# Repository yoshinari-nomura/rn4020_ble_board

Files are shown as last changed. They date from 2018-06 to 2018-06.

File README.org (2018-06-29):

#+TITLE: RN4020 を使った iBeacon 作成
#+AUTHOR: 乃村 能成
#+EMAIL:
#+DATE: 2017-06-30
#+OPTIONS: H:3 num:2 toc:nil
#+OPTIONS: ^:nil @:t \n:nil ::t |:t f:t TeX:t
#+OPTIONS: skip:nil
#+OPTIONS: author:t
#+OPTIONS: email:nil
#+OPTIONS: creator:nil
#+OPTIONS: timestamp:nil
#+OPTIONS: timestamps:nil
#+OPTIONS: d:nil
#+OPTIONS: tags:t
#+TEXT:
#+DESCRIPTION:
#+KEYWORDS:
#+LANGUAGE: ja
#+LATEX_CLASS: jsarticle
#+LATEX_CLASS_OPTIONS: [a4j,dvipdfmx]
# #+LATEX_HEADER: \usepackage{plain-article}
# #+LATEX_HEADER: \renewcommand\maketitle{}
# #+LATEX_HEADER: \pagestyle{empty}
# #+LaTeX: \thispagestyle{empty}

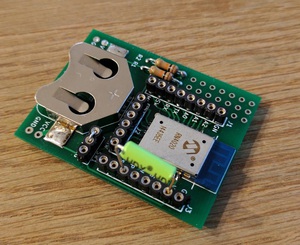
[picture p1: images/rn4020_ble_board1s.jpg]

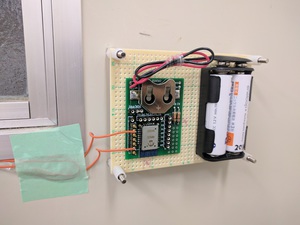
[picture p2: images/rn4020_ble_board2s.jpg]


* はじめに
  Microchip の RN4020 は，Bluetooth Low Energy 機器作成に必要な機能を1チップに収めた
  非常に使いやすいマイコン製品です．以下の特徴があります．

  + 消費電力非常に小さい
  + 簡易的ながら柔軟なユーザスクリプトを記述できる
  + 特別な開発環境(コンパイラ)の整備が不要

* ディレクトリ構成
  + file:TECHNICAL-MEMO.org :: 作成時に気付いたことなどのメモやノウハウ
  + file:README.org :: このファイル
  + file:datasheet/ :: RN4020 のデータシート
  + file:images/ :: 回路図(PDF)，CADの3Dイメージ，設置例写真など
  + file:kicad/ :: 回路図，基板作成CADのデータ
    + file:garber/ :: PCB注文時のzipファイルと作成用シェルスクリプトなど
  + file:rn4020_scripts/ :: RN4020に書込むユーザスクリプト例

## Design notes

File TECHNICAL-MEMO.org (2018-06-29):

#+TITLE: RN4020 を使った beacon 作成メモ
#+AUTHOR: Yoshinari Nomura
#+EMAIL:
#+DATE:
#+OPTIONS: H:3 num:2 toc:nil
#+OPTIONS: ^:nil @:t \n:nil ::t |:t f:t TeX:t
#+OPTIONS: skip:nil
#+OPTIONS: author:t
#+OPTIONS: email:nil
#+OPTIONS: creator:nil
#+OPTIONS: timestamp:nil
#+OPTIONS: timestamps:nil
#+OPTIONS: d:nil
#+OPTIONS: tags:t
#+TEXT:
#+DESCRIPTION:
#+KEYWORDS:
#+LANGUAGE: ja
#+LATEX_CLASS: jsarticle
#+LATEX_CLASS_OPTIONS: [a4j,dvipdfmx]
# #+LATEX_HEADER: \usepackage{plain-article}
# #+LATEX_HEADER: \renewcommand\maketitle{}
# #+LATEX_HEADER: \pagestyle{empty}
# #+LaTeX: \thispagestyle{empty}

* 部品の選定
** RN4020 ← これを選定
   + 秋月で買える ( [[http://akizukidenshi.com/catalog/g/gM-10066/][RN4020-V/RM123]] ) 1,000円ぐらい
   + MCU なしでも簡単な回路でセンサと連携できそう
   + 価格と入手性がいい

** konashi/koshian
   + [[https://www.ux-xu.com/product/konashi][konashi | ユカイ工学]]
   + [[http://eleshop.jp/shop/g/gFAE311/][共立でも買える]]
   + コネクタは Hirose Electric Co Ltd DF40C-20DP-0.4V
   雑感
   + 共立には，koshian がない?
   + スイッチサイエンスには，koshian がない?
   + マクニカの拡張ボードにはピンヘッダが実装されてて面倒そう
   + 秋月には konashi のみ?
   + konashi で開発して koshian (安価) を実機に載せるのは便利そう
   + 高機能過ぎて消費電力が大きそうなのが問題
     →  [[https://www.hirotakaster.com/technology/koshian-wiced-%25E3%2581%25A7%25E9%2596%258B%25E7%2599%25BA/][Koshian & WICED で開発]] ならばOK?

* Beacon って何?
** iBeacon (Apple)
*** 導入や製品情報
    + [[https://www.slideshare.net/fumisato/googleeddystone][Googleのオープンなビーコン規格「Eddystone」とはなんなのか？]]
      + いいスライド．iBeacon の事も書いてある．ホントは，Eddystone が面白いのだが，
        RN4020 は，ファームウェア書換えなきゃいけない(Windowsが必要)のが面倒．
    + [[http://www.aplix.co.jp/product/mybeacon/][MyBeacon®シリーズ｜株式会社アプリックス]]

*** iBeacon のフォーマット
    + [[https://support.kontakt.io/hc/en-gb/articles/201492492-iBeacon-advertising-packet-structure][iBeacon advertising packet structure]]
      + 9 bytes iBeacon prefix
        + 前5バイトは RN4020 ではいじれない．([[https://www.microchip.com/forums/m909686.aspx][RN4020 Eddystone]])
        + 後ろ4バイトを 4C 00 02 15 とすると，iBeacon
      + 16 byte UUID
      + 2 bytes Major
      + 2 bytes Minor
      + 1 byte TX power

      : 4C 00 02 15 (16bytes UUID) (2bytes Major) (2bytes Minor) (1byte Power)
      : 4 + 16 + 2 + 2 + 1 = 25

      + 例 :: 4C000215 467FD32695D242F2BBBC5C8F4610B120 0001 0002 C0

    + Major, Minor, TX power を適当に(センサの値などに応じて)変えて送ることで，
      ビーコンから何らかの数を送れそう．

*** アドバタイズの間隔と消費電力の関係
    + [[https://qiita.com/ksksue@github/items/0811fd62bd970fa93337][BLE/iBeacon 消費電力ハック - Qiita]]
    + [[http://d.hatena.ne.jp/shu223/20141210/1418171949][アップルによるBluetoothアクセサリの設計ガイドラインに書かれていたこと - Over&Out その後]]
      本来の用途のビーコンとして使おうとすると，結構間隔を短かくしなければならないので，消費電力もそれなり．

** Eddystone/Physical Web (Google)
*** 導入や解説
    + [[http://physicalweb.jp/][Physical Webとは？ | Physical Webの概要とiBeaconとの違い]]
    + [[http://dev.classmethod.jp/smartphone/eddystone/][GoogleのEddystoneとはなんなのか ｜ Developers.IO]]
      UID は，ドメイン名の SHA1 の先頭10バイトらしい?
    + 製品例: [[http://direct.sanwa.co.jp/ItemPage/MM-BTPW1][Physical Web Beacon MM-BTPW1の販売商品 |通販ならサンワダイレクト]]
    + [[http://kitak.hatenablog.jp/entry/2016/03/05/233832][Android ChromeでPhysical Webを試した - kitak.blog]]
    + [[https://developers.googleblog.com/2015/07/lighting-way-with-ble-beacons.html][Google Developers Blog: Lighting the way with BLE beacons]]
    + [[http://google.github.io/physical-web/][The Physical Web Top]]
    + [[http://google.github.io/physical-web/get-started#bluetooth-low-energy-ble-beacons][The Physical Web (bluetooth-low-energy-ble-beacons)]]

*** フォーマット
    + [[https://developers.google.com/beacons/eddystone#full_support_for_eddystone][Eddystone format]]
    + [[https://github.com/google/eddystone/blob/master/protocol-specification.md][eddystone/protocol-specification.md at master · google/eddystone]]
    + [[http://dev.classmethod.jp/smartphone/eddystone/][GoogleのEddystoneとはなんなのか ｜ Developers.IO]]
    + Eddy Stone の URL タイプのフォーマット:
      : AAFE {SIZE} AAFE
      この後にFrametype=10, TXPower=C0, URLscheme=0x03(https://) + 残り17バイト(ASCII)が入れられる．
      例えば， https://quickhack.net/es をビーコンで飛ばそうとすると:
      : "quickhack.net/es".each_byte.map{|b| "%X" % b}.join => 7569636b6861636b2e6e65742F6573
      なので，
      : AAFE 11 AAFE 10C003 71 7569636b6861636b2e6e65742F6573
      となる．

*** RN4020 で Eddystone を実装しようとすると，
    [[https://electronza.com/rn4020-eddystone-beacon-tutorial/3/][RN4020: Eddystone beacon tutorial - Page 3 of 3 - Electronza]] NZ コマンドは firmware 1.33 以降が必要．
    + [[http://www.microchip.com/wwwproducts/en/RN4020][RN4020 - Bluetooth Module]] → Documentation → Software  [[http://microchipdeveloper.com/ble:rn4020-app-example-dfu-uart][RN4020 Device Firmware Update (UART) - Developer Help]]
      → RTS/CTS の使える RS232C + Windows が必要
    + [[http://microchipdeveloper.com/ble:rn4020-app-example-dfu-ota][RN4020 Device Firmware Update (OTA) - Developer Help]]
      → iOS のツールは，古くて，1.33 に対応していない!
    + [[http://www.microchip.com/forums/m978113.aspx][RN4020 Firmware Update to 1.33, using DFU-OTA. How to setup sender/receiver? | Microchip]]
      + これでいけそう?

** Android 用 Beacon デバッグ用 App
  + [[https://play.google.com/store/apps/details?id=de.flurp.beaconscanner.app][iBeacon & Eddystone Scanner]]
  + [[https://play.google.com/store/apps/details?id=com.google.android.apps.location.beacon.beacontools][Beacon Tools]] :: 
    Proximity Beacon API で Beacon を登録するアプリ
    解説: [[http://juggly.cn/archives/184531.html][Google，開発者向けのBLEビーコン管理アプリ「Beacon Tools」をリリース]]
  + [[https://play.google.com/store/apps/details?id=com.uriio][Beacon Toy]] :: 
    Google 推奨 App -  Android 端末で Eddystone/iBeacon のフリをさせるツール

** コード例
   + [[http://qiita.com/chibatching/items/0cb0eaad42607a4f5754][Google発のBeacon用オープンフォーマットEddystoneをAndroidで触ってみた - Qiita]]

** Nearby Message API + Proximity Beacon API
   + [[https://developers.google.com/nearby/messages/overview][Overview Nearby Messages API]]
   + [[https://developers.google.com/beacons/proximity/guides][Overview Proximity Beacon API]]
   + [[http://recruit.gmo.jp/engineer/jisedai/blog/eddystone/][Eddystone ビーコンへのデータ登録・取得方法の紹介]]
   + [[http://qiita.com/chibatching/items/8435fd1a98a0b7d3da96][Nearby Messages APIとEddystoneを連携する - Qiita]]

   おおざっぱな仕組みとしては，
   1) Proximity Beacon API で Google に自分の Beacon の情報を登録しておく
   2) Android が登録された Beacon に近づくと Nearby Messsage API 経由で  Beacon の情報を受け取る
   3) Beacon の情報を Proximity Beacon API で取得して，詳細情報を得る
   4) 詳細情報を popup する

   この流れを使うことで，Beacon の持つ情報だけでなく，その Beacon に紐付けて
   Google に登録した情報を取得できる．
   情報提供側は，Beacon そのものを変更することなく，送りたいメッセージを
   Proximity Beacon API で変更できる．

* Raspberry PI や Mac で iBeacon のアドバタイズを受信する
** Ruby による実装
   1) [[https://github.com/sdalu/ruby-ble/blob/master/ble.gemspec][ruby-ble/ble.gemspec at master · sdalu/ruby-ble]]
   2) [[https://github.com/RadiusNetworks/scanbeacon-gem][RadiusNetworks/scanbeacon-gem: A Ruby gem for scanning beacons]] ← これを選定
      インストール:
      : apt-get install bluez libbluetooth-dev ruby-dev
      : gem install scan_beacon

** Node.js による実装
   1) [[http://qiita.com/yuyakato/items/a1225154445520dc2db3][Raspberry PiにnodebrewでNode.jsをインストールする - Qiita]]
   2) [[http://qiita.com/yuyakato/items/739443960fac2668f4a3][Raspberry PiでiBeaconを受信する（Node.js + bleacon） - Qiita]]
   3) [[http://wondergadget.hatenablog.com/entry/2014/12/23/121400][BLEのアドバタイズを受信する - wonder gadget]]

* Android で Beacon を検知するアプリを作る (AltBeacon - Android Beacon Lib)
  + http://altbeacon.org/
  + http://altbeacon.github.io/android-beacon-library/index.html
  + サンプル: [[https://github.com/AltBeacon/android-beacon-library-reference][AltBeacon/android-beacon-library-reference: A reference application for the Android Beacon Library]]

  RegionBootStrap でバックグラウンド処理では，捉えた個々のBeaconを判別できないので，
  http://altbeacon.github.io/android-beacon-library/samples.html にあるフォアグラウンドの手法を用いて
  実装したほうがいいという話:  http://stackoverflow.com/questions/25768326/how-to-get-visible-beacons-from-the-regionbootstrap-altbeacon-method

  MonitoringLisner + service で行く方法:
  http://stackoverflow.com/questions/32632881/estimote-monitoring-mutiple-beacons-at-same-time-android

  BootStrap で didEnterRegion を捉えてから，その中で
  startRangingBeaconsInRegion して監視を開始．
  RangeNotifier インタフェースの didRangeBeaconsInRegion で個々の Beacon の状態を管理する方法:
  http://altbeacon.github.io/android-beacon-library/distance-triggering.html

* RN4020 開発
** 開発環境の整備
   + これを買って: [[https://www.amazon.co.jp/dp/B01LXHQIF0][CP2102 USB UART TTL モジュール]]
   + ドライバのインストール: [[http://jp.silabs.com/products/development-tools/software/usb-to-uart-bridge-vcp-drivers][VCP ドライバ Silicon Labs]]
     ドライバ名は， =/dev/cu.SLAB_USBtoUART= になる

** マニュアル，データシート
  + [[http://www.microchip.com/wwwproducts/en/RN4020][RN4020 - Bluetooth Module]]

  + [[http://ww1.microchip.com/downloads/en/DeviceDoc/50002279B.pdf][RN4020 Bluetooth Low Energy Module Data Sheet - 50002279B.pdf]]
    COPY: [[file:doc/50002279B.pdf][Datasheet]]

  + [[http://ww1.microchip.com/downloads/en/devicedoc/70005191b.pdf][RN4020 Bluetooth Low Energy Module User’s Guide - 70005191b.pdf]]
    COPY: [[file:doc/70005191b.pdf][Users Guide]]

  + [[http://www.microtechnica.tv/support/manual/clickble_man.pdf][Taro-CLICK-BLE - clickble_man.pdf]]

** 参考になりそうな初期情報ページ
   + [[http://illmaticindustries.com/?p=525][お手軽BLEモジュール RN4020の消費電力 | illmatic工業]]
   + [[http://meuse.co.jp/%25E9%259B%25BB%25E5%25AD%2590%25E5%25B7%25A5%25E4%25BD%259C/ble%25E3%2583%25A2%25E3%2582%25B8%25E3%2583%25A5%25E3%2583%25BC%25E3%2583%25AB-rn4020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][BLEモジュール RN4020を試す | 電子工作 | Meuse Robotics]]

** アプリケーションノート
   + [[http://ww1.microchip.com/downloads/jp/AppNotes/00001861A_JP.pdf][Using RN4020 for Bluetooth Smart Communication.fm - 00001861A_JP.pdf]]
   + [[http://www.microchip.com/wwwAppNotes/AppNotes.aspx?appnote=en573446][AN1906: Bluetooth Low Energy Digital Pedometer Demo Design]]

** RN4020 疑問
  + [[http://www.microchip.com/forums/m914058.aspx][RN4020 Maximum Analog Input Voltage | Microchip]]
  + [[http://www.microchip.com/forums/m846328.aspx#846328][RN4020 Device Name | Microchip]]
  + [[http://www.microchip.com/forums/m851785.aspx#851785][RN4020 identification by android app | Microchip]]

** RN4020 省電力 Deep SLEEP 問題
   + [[http://www.microchip.com/forums/m938292.aspx][RN4020 alone, without MCU, in Script Mode, Timer TMR1 not triggering in Deep Sleep mode | Microchip]]
   + [[http://www.microchip.com/forums/m845882-p2.aspx][RN4020 - anomalies such as drawing more current than expected | Microchip]]

   + [[http://microchip.wikidot.com/ble:rn4020-power-states][RN4020 Power States - Developer Help]]
     + UART_RX をオープンにしておくと Deep sleep の消費電力が上がるので，
       10kΩで pull-up しておくこと
     + WAKE_SW は 内部 pull-down されていないので 10kΩで pull-down して
       おくこと

   + [[http://microchip.wikidot.com/ble:rn4020-mcu-interface][RN4020 MCU Interface - Developer Help]]
     + WAKE_SW は，内部プルダウンされていないので，
       10kΩで pull-down しておく必要がある．

  + 結論 設定覚え書き:
    + CMD/MLDP :: Lo (CMDモード) → 内部 pull-down なので解放でも OK
    + UART_RX :: 10kΩで pull-up (解放だと Deep Sleep 時の消費電力が大きい)
    + WAKE_HW :: Lo → 内部 pull-down なので解放でも OK
    + WAKE_SW :: 購入した素の状態の場合， Hi (VCC) にしておく．
                 SB,0 で RN4200 を 2400bps にしてリセットした後は，
                 Lo (Deep Sleep) (10kΩで pull-down)．
** Mac と自作 RN4020 ボードを接続して kermit からスクリプトを書込む
   + brew install c-kermit
   + TX と RX をクロスで PC につなぐ (3.3v)
   + スイッチを PRG 側にする
   + .kermrc で，以下の設定
     #+BEGIN_EXAMPLE
       ;; CP2102 Silicon Labs
       set line /dev/cu.SLAB_USBtoUART

       set carrier-watch off
       ;; set speed 9600
       set speed 115200
       set parity none
       set terminal bytesize 8
       set terminal cr-display crlf
       set flow-control none
     #+END_EXAMPLE

   + 接続して最初の操作は，以下のとおり:
     最初は，115200bps なので，2400bps に変更して，RN4020 をリブート．
     #+BEGIN_EXAMPLE
       +      // Echo on
       SF,1   // Factory reset
       SB,0   // set terminal 0=2400bps 4=115200bps (default)
       R,1    // Reboot
     #+END_EXAMPLE
     この後，kermit をコマンドモードに落として (Ctrl-\ c)
     : set speed 2400
     として再接続．

   + スクリプトの書込み:
     #+BEGIN_EXAMPLE
       +     // Echo on
       WC    // 既に書込まれちるスクリプトをクリア
       WW    // スクリプト書込みモードに入る (ESCで終了)
     #+END_EXAMPLE
     ここで，例えば，[[file:rn4020_scripts/rn4020-read-digital-input.txt][rn4020-read-digital-input.txt]] をターミナルにコピペして，終わったら
     ESC で抜ける．

     #+BEGIN_EXAMPLE
       LW // スクリプトをリスト表示で確認
     #+END_EXAMPLE

   + RN4020 ボードのスイッチを RUN 側にする

   + 実行
     #+BEGIN_EXAMPLE
       SR,01000000 // Run script after power on
       R,1         // Reboot
     #+END_EXAMPLE
     これで電源を切って，電池につなぎなおす．

   + kermit からの実行と停止
     + WR コマンドでスクリプト実行
     + WP コマンドでスクリプト停止

** スクリプト例の解説
   + 5秒に1回，AI0 (アナログ入力) を読んで，1秒間アドバタイズする．
     (AI0 は，0x0042-0x0532 ぐらいl 66mV - 1.33V ぐらいの値になる)
     # ruby -e 'puts 0x4c4b40' => 5000000
     #+BEGIN_EXAMPLE
       # 電源投入時に以下を実行
       @PW_ON

       # タイマ1を即 (1us) 後に起動
       SM,1,00000001

       # タイマ1発火時に以下を実行
       @TMR1

       # アドバタイズを一旦止める
       Y

       # AI0 につながった，Cds (光) センサを読んで，$VAR1 に代入
       $VAR1 = @I,0

       # BLE パケットのアドバタイズパケットを作成
       #
       # iBeacon の場合は，以下の通りになる:
       #  4C000215 (16bytes UUID) (2bytes Major) (2bytes Minor) (1byte Power)
       #
       # HEAD  = 4C000215 (Apple iBeacon では固定)
       # UUID  = 467FD32695D242F2BBBC5C8F4610B120 (Beacon の個体毎に違う値にすること)
       # MAJOR = 00 $VAR1 ($VAR1 は，実際の値(1-byte) に展開される)
       # MINOR = 00 00
       # POWER = C9 (自身の送信出力．この値と実際の受信強度から距離が推定できる)
       #
       N,4C000215467FD32695D242F2BBBC5C8F4610B120$VAR10000C9

       # 100ms (0x0064) 間隔でアドバタイズパケットを 1000ms (0x03E8) の間送出し続ける
       A,0064,03E8

       # タイマ1を timer1 5,000,000us (0x004C4B40) つまり5秒後に発火させる
       SM,1,004C4B40
     #+END_EXAMPLE

* 類似製品例
  + [[http://japanese.engadget.com/2016/08/23/1000-iot-leafee-mag-makuake/][窓の閉め忘れをスマホからチェック。1000円台のIoTデバイス『leafee mag』、Makuakeに登場 - Engadget Japanese]]
  + [[http://www.runele.com/ca1/23/][FRISKケースに入るBLE112基板 REBLE112FR - ランニングエレクトロニクス]]

* 基板作成 - KiCadとPCB注文
** KiCad 概要
   [[http://kicad-pcb.org/][PCB CAD KiCad]]
   + KiCad のヘルプから，チュートリアルが読める
     [[http://kicad-pcb.org/help/documentation/][Documentation | KiCad EDA]]
   + [[http://kicad.jp/][オープンソースの PCB CAD 日本ユーザコミュニティが優しい]]
   + [[https://tech.nosuz.jp/2015/12/kicad-info/][KiCadの情報源メモ]] が役立つ
   + [[http://www.slideshare.net/soburi/kicad-53622272][KiCadで雑に基板を作る チュートリアル]] slide

   + [[https://github.com/nosuz/kicad-lib][nosuz/kicad-lib]]

** 操作/ノウハウ
   → [[https://tech.nosuz.jp/2015/09/kicad-footprints-on-github/][Githubに公開されているKiCadのフットプリントを使用する方法]]
   操作メモ
   + コンポーネント/テキストの移動 :: M
   + コンポーネント位置ドラッグ(配線維持したまま) :: G
   + 回転 :: R
   + コピー :: C
   + 配線 :: W
   + 定数変更 :: V
   + 部品追加 :: A

** 秋月の基板サイズ
   + C基板: 72x47.5mm
   + D基板: 47.5x36mm

** 標準的なデザインルール
   + 最小配線幅 0.2mm
   + 最小ビア径 0.8mm
   + 最小ビアドリル 0.4mm
   + クリアランス最小 0.1542mm (10milぐらいまで好みで)

** freeroute
  + [[http://atmel.client.jp/kicad.html][kicad Mac 日本語化]]
  + [[http://kerikeri.top/posts/2016-04-22-freerouting/][KiCadで自動配線 - KERI's Lab]]

  + [[http://amichalec.net/2015/10/kicad-upgrade/][Kicad upgrade: push & shove and freerouting revisited | amichalec.net :: homepage]]
    1) Download Freerouter from this mirror
       https://github.com/freerouting/freerouting
    2) Extract freerouting-master.zip/binaries/freerouting.jar
    3) mv freerouting.jar /Applications/Kicad/pcbnew.app/Contents/MacOS/freeroute.jar

** PCB 注文
   + [[https://www.switch-science.com/pcborder/techguide/][技術ガイド - スイッチサイエンス]]
   + [[https://www.seeedstudio.com/fusion_pcb.html][Fusion PCB/PCBA - Seeed Studio]]
   + [[http://d.hatena.ne.jp/inajob/20160312][RakuChordの回路を発注してみた。 - INAの日記]]
   + [[http://microcraft.blog.fc2.com/blog-entry-20.html][KiCadデザインルール設定 - 小さな工作室]]
   + [[http://blog.livedoor.jp/jun_dime/archives/51842909.html][続・kicadを使ってfusion PCBへ発注してみた。 : だいむのblog]]
   + [[http://support.seeedstudio.com/knowledgebase/articles/422482-fusion-pcb-order-submission-guidelines][Fusion PCB Order Submission Guidelines – Feedback &amp; Ideas for seeed]]
   + [[http://clockworks01.blogspot.jp/2015/07/kicadfusion-pcb.html][KICADでガーバー出力し、Fusion PCB へ発注する手順]]
   + [[https://forum.kicad.info/t/seeedstudio-fusion-rules/811][Seeedstudio fusion rules - Manufacturing - KiCad.info Forums]]

* Linux の hcitool で BLE パケットの受信を確認する
  : sudo hcitool lescan

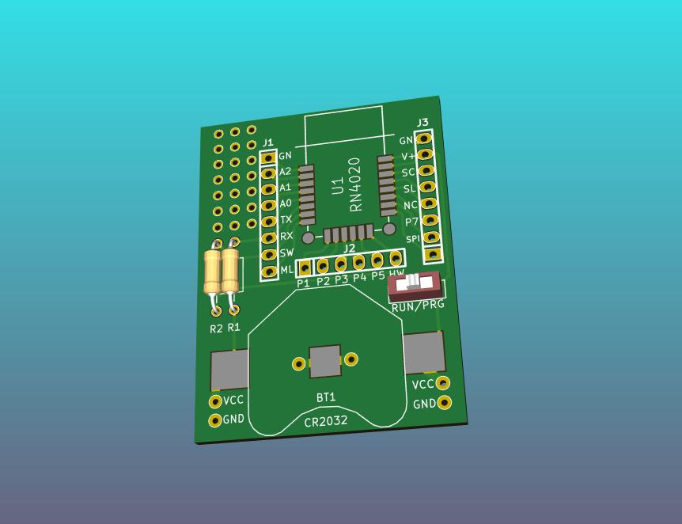
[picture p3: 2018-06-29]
images/rn4020_breakout-3d-image.jpg

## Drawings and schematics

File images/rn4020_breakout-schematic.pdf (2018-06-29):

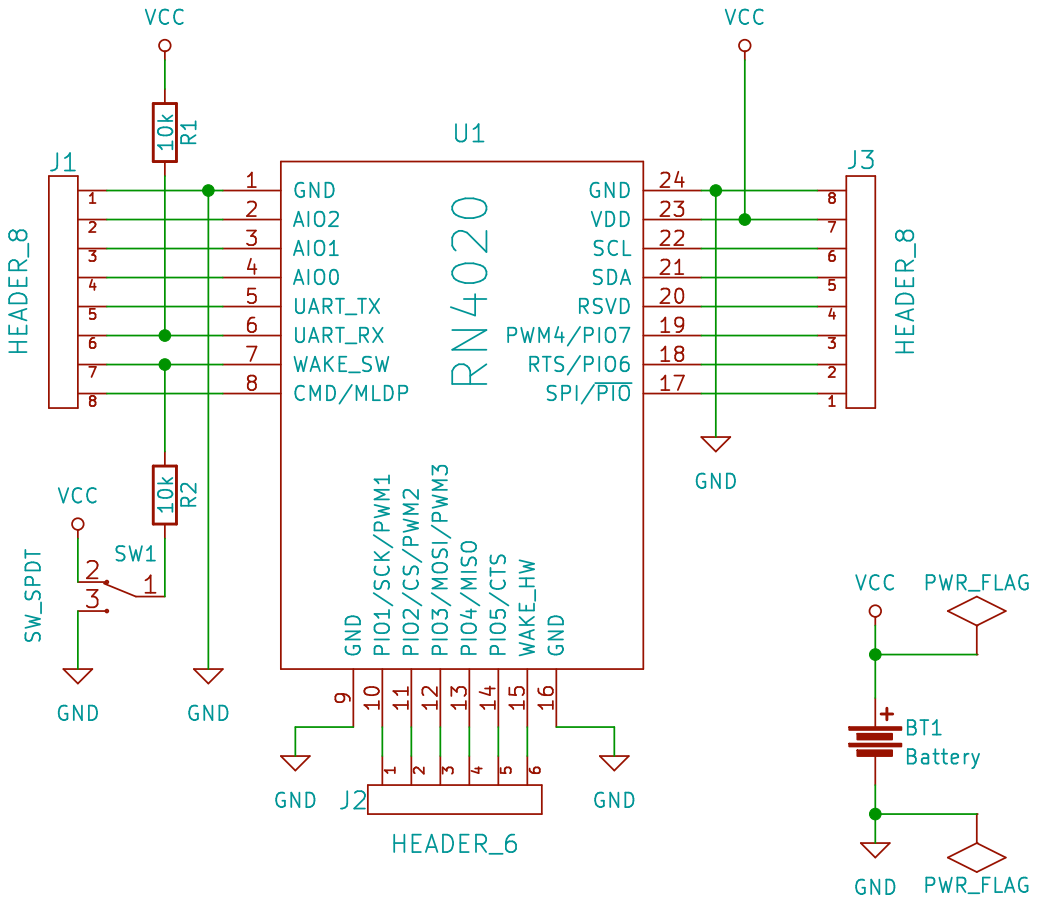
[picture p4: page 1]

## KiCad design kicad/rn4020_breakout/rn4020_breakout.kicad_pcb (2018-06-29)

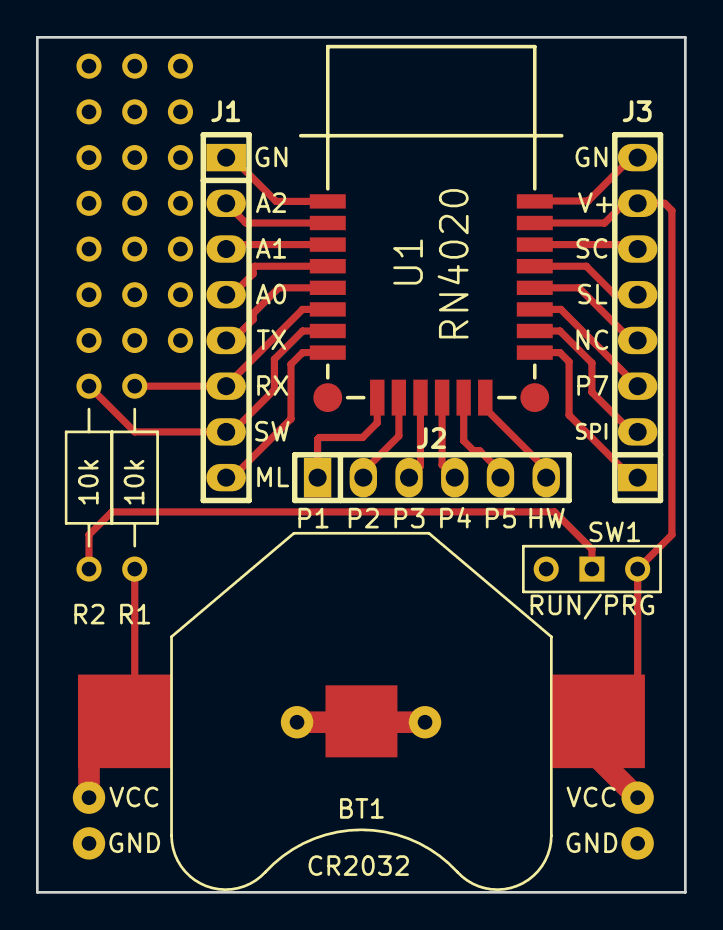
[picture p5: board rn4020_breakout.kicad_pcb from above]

Board: 2 copper layers, 36.0 x 47.5 mm, 8 parts (0 on the bottom side), 22 nets.

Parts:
BT1: CR2032; BC-2001
J1, J3: HEADER_8; pin_socket_8
J2: HEADER_6; pin_socket_6
R1, R2: 10k; Resistor_Horizontal_RM10mm
SW1: RUN/PRG; SW_Micro_SPDT
U1: RN4020

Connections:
GND: BT1.2, J1.1, J3.8, SW1.3, U1.1, U1.24
unnamed: J1.2, U1.2
unnamed: J1.3, U1.3
unnamed: J1.4, U1.4
unnamed: J1.5, U1.5
unnamed: J1.6, R1.2, U1.6
unnamed: J1.7, R2.1, U1.7
unnamed: J1.8, U1.8
unnamed: J2.1, U1.10
unnamed: J2.2, U1.11
unnamed: J2.3, U1.12
unnamed: J2.4, U1.13
unnamed: J2.5, U1.14
unnamed: J2.6, U1.15
unnamed: J3.1, U1.17
unnamed: J3.2, U1.18
unnamed: J3.3, U1.19
unnamed: J3.4, U1.20
unnamed: J3.5, U1.21
unnamed: J3.6, U1.22
unnamed: R2.2, SW1.1
VCC: BT1.1, J3.7, R1.1, SW1.2, U1.23
